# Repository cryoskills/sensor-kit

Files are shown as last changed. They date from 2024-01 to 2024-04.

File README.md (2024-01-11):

# Cryoskills 2024 - Sensor Kit
This repository contains the design notes, schematics, EDA files (KiCad), fabrication documents and firmware for the CryoSkills sensor kit.

## Folder Structure

- `design_notes/`: design notes and documentation.

- `cad/`: electronic and mechanical design files, separated into:
    - `kicad/` schematic and PCB layout files
    - `freecad/` mechanical design files

- `fabrication/`: resources required to purchase, fabricate and assemble a sensor kit (bill of materials, Gerber files, drawings, etc.).

- `firmware/`: complete and skeleton firmware for the sensor kit.

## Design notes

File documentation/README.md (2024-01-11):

See Word document for initial design notes:

    ColdEnvironmentSkillsCourse/Course content/SensorKit/SensorKit_DesignNotes.docx

Cut-down version exists in ./documentation/DesignNotes.docx

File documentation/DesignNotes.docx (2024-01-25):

# CryoSkills Sensor Kit

# System-level schematic

Solar Panel

Regulator

Battery

QWIIC (I²C) Sensors

Analogue Temp. Sensor

Micro-controller

(i.e. Feather M0 Adalogger)

SD Card

Wireless

Modem

Antenna

Weatherproof housing

Solar Regulator

Realtime clock

# Subsystems

## Power (Battery & Solar)

The power supply for the sensor kit is composed of a 12V lead-acid battery and a 12V 5W solar panel, connected to the battery through a EP Solar 5a charge controller.

Item | URL
12V 1.2Ahr lead-acid battery | https://uk.rs-online.com/web/p/lead-acid-batteries/1501558?gb=s
12V 5W solar panel | https://www.sunstore.co.uk/product/12v-5w-monocrystalline-solar-panel/
EP Solar 5a Charge Controller | https://www.sunstore.co.uk/product/ep-solar-5a-charge-controller-with-usb-output/

Table 1 - Power system components

The solar charge controller has a maximum rated battery current of 5A and maximum PV (panel) input of 30V. The mounting hole sizes are M4.5 (assumption of mm) and terminal sizes are 2.5mm² which require wire diameter of less than 1.784mm (AWG of 14 or greater). The charger user manual recommends that cables should satisfy 3.5A/mm² current density – AWG 14 can therefore accommodate 5.25A.

The battery terminals are tabs with width 4.75mm and length 6.35mm, hence a 5mm spade connector with AWG 14-16 crimp terminal is sufficient.

Finding it hard to find appropriate 4.75mm tabs in red/blue or red/black with matched 2.5mm² CSA – go with blue which has 2.5mm² max CSA.

Component | Details | Supplier | Order Code
Red 16AWG Cable | 100m | Farnell / SW | 1204343 (https://uk.farnell.com/lapp-kabel/4520041/wire-h07v-k-red-1-5mm-100m/dp/1204343)
Black 16AWG Cable | 100m | Farnell / SW | 1204340 (https://uk.farnell.com/lapp-kabel/4520011/wire-100m-1-5mm2-copper-black/dp/1204340)
Red Crimp Terminal | 4.8mm(W), 12A, 16-14AWG | Farnell / SW | 3384774 (https://uk.farnell.com/pro-power/stfdd1-187-8/female-push-on-red-12a-4-8-x-0/dp/3384774)
Blue Crimp Terminal | 4.8mm(W), 16A, 16-14AWG | Farnell / SW | 3384777 (https://uk.farnell.com/pro-power/stfdd2-187-8/female-push-on-blue-16a-4-8-x/dp/3384777)
Red Ferrule | 16 AWG 10mm | Farnell / SW | 3383565 (https://uk.farnell.com/pro-power/pet1515/german-single-ferrule-1-50mm-red/dp/3383565)
Black Ferrule | 16 AWG 10mm | Farnell / SW | 4161844 (https://uk.farnell.com/pro-power/pp01538/french-single-ferrule-1-50mm-black/dp/4161844)
Fuse Holder | 16 AWG, Red, 5x15mm Fuse, | RS Pro / SW | 849-5594 (https://uk.rs-online.com/web/p/fuse-holders/8495594)
1A Fuse | 5x15mm | - | -

Alternatively, consider using automotive blade style fuse holder & fuse – need to check options. Ideally should satisfy current rating <5A and AWG 16 gauge cable.

These place a requirement on the screw terminals used on the sensor kit PCB – they must be able to accept 1.5mm² CSA ferrules.

### Battery Capacity

The battery capacity is calculated for an on period of 2s and a sleep period of 58s, resulting in a total measurement interval of 60s. For a 24 hour period, this would yield 1440 measurements.

The average current consumed is calculated as

I=(I_(sleep) t_(sleep) +I_(peak) t_(peak) )/T_(period)

Hence for the values given in Table 2, the average current is 4.76mA at 3V3 and 6mA at 12V (solar charger). Hence the power consumed is 15.7mW (load) and 72mW (self consumption) or a total of 87.7mW. Over a period of 24hours, this requires 2.1Wh of energy. Assuming the battery is derated by 50% due to cold weather, the actual energy requirement is 4.2Wh, which at 12V equates to a battery capacity of 0.35Ah. A 12V 1.2Ah battery specified should be sufficient to run the sensor for the 24-hour period.

Component | Sleep Current (mA) @ 3V3 Vcc | Peak Current (mA) @ 3V3 Vcc | Time-enabled per cycle (s)
Adafruit Feather M0 | 2 | 20 | 2
Wireless module | 0.001 (sleep mode) | 120 | 1
I2C atmospheric sensor | 0.0000002 | 0.000714 | 1
PT1000 temp. sensor | 0.000002 | 0.210 | 1
DSB1820 temp.sensor | 0.00000075 | 1.5 | 1
I2C light sensor | 0.000005 | 0.220 | 1
Charge controller | <6 (@12V) | <6 @(12V) | Always-on
| ~8 | ~150

Table 2 - Current consumption based on subsystems

### Solar Charge Controller

Wiring of the solar charge controller is given by the (terrible user manual (https://www.sunstore.co.uk/wp-content/uploads/2017/02/LS-EU%20Manual.pdf) supplied) diagram in Figure 1.

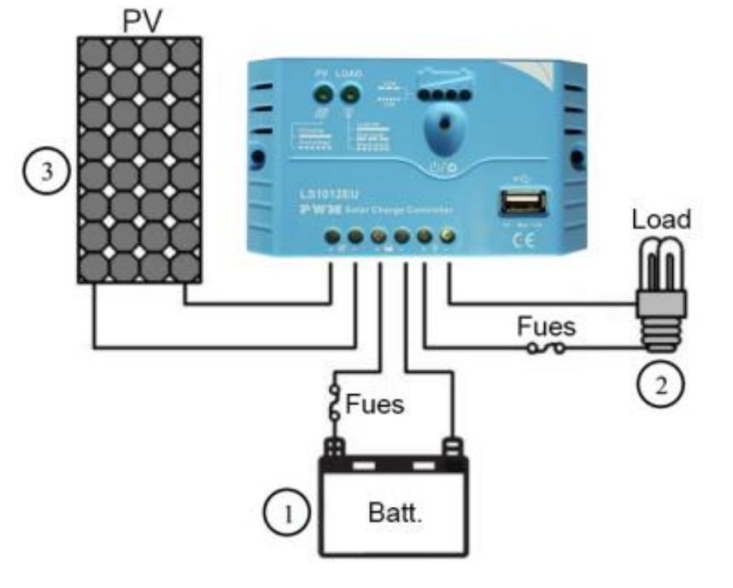
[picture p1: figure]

Figure 1 - EP Solar 5a Charge Controller wiring diagram

### INA3221 Power Meter

The Texas Instrument INA3221 (https://www.ti.com/product/INA3221) integrates a high-side ADC which can be used as a power meter. To integrate with the sensor kit, using the three available channels we can assess power from the solar panel, battery power (charge or discharge) and the power draw of the load.

Note: The rated open circuit voltage of the panel is 21.9V so this is within the maximum input voltage however it is perhaps prudent to add some voltage protection at the panel input in-case an alternative panel is used?

Appropriate current sense resistors need to be selected for each of the channels. The shunt voltage limits for the INA3221 are ±163.8mV and the maximum input voltage at any port is 26V.

We assume the peak current into the sensor kit will be on the order of 0.2A (rounded up from 0.15A peak consumption during radio transmission). With a 0.2 Ohm resistor, this equates to a shunt potential difference of 40mV (30mV) which uses approximately 10% of the full-scale voltage range.

The maximum charge current for the RS Pro lead-acid battery is listed as 0.36A, hence with the same 0.2 Ohm resistor as above, we yield a potential difference of 72 mV.

This appears to be a reasonable value to use across the application – the everythingpi.co.uk evaluation board uses 0.1 Ohm, which I assume is to accommodate for slightly higher average load currents.

A provisional wiring diagram for integrating the INA3221 power meter into the sensor kit is shown in Figure 2. This results in a total of 6x screw terminals being present on the sensor kit board, one each for the solar panel and battery and then an additional to wire the load to the solar controller. An external 6-way connector (i.e. 2x 5-way Wago?) is also necessary to provide a common ground for the panel, battery, charge controller and load.

HellermanTyton 8-way splice for 1mm² to 2.5mm² common splice (RS Stock No. 124-2530).

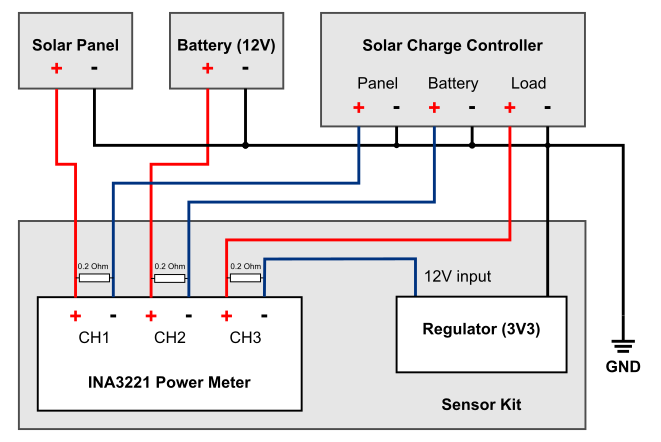
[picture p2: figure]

Figure 2 - Wiring diagram for sensor kit using INA3221 power meter with solar panel, 12V battery and solar charge controller. (Note add connector indication to diagram…)

### Linear (LDO) vs Buck Voltage Regulator

If there is a sufficient pin-for-pin replacement (3-pin 100mil, Vin-GND-Vout) for the Multicomp Pro drop-in MP-K78L03-500R3 DC/DC regulator then participants can have the choice/compare the performance of linear vs. buck boost regulated instrument using data from the INA3221. The higher efficiency DC/DC converter should draw less current from the 12V supply and hence less power.

### Mechanical Considerations (Panel)

Mounting for solar panel up to M7.5 screws through back of panel separated by 128mm height and 156mm width.

## Microcontroller and Datalogger

An Adafruit Feather M0 Adalogger has been selected as the microcontroller for the sensor kit because of the integrated MicroSD slot and compatibility with existing code. It is based on the Amtel SAMD21G18 ARM Cortex M0 processor.

Logic levels are at 3V3.

### Power Considerations

The sensor kit board has its own 3V3 regulator from the battery supply, hence the Adalogger can be powered directly from the output of the system regulator rather than its on-board 3V3 LDO (SPX3819-3.3 (https://assets.maxlinear.com/web/documents/spx3819.pdf)). This requires that the internal Adalogger 3V3 regulator is disabled by tying EN to GND and ensuring the 3V pin is connected to the output of the system regulator.

If it was desirable to use the USB to power the sensor kit (i.e. during development or testing) then a header can be fitted to connect the USB bus voltage from the Adalogger board to the sensor kit input.

Note: Either care must be taken to ensure that the battery isn’t connected at the same time as the USB power is enabled, or a physical switch is implemented on the board to ensure that this can’t take place.

For now, the second option is implemented with a slide switch to alternate between battery or USB power, using an RS Pro 734-7334 (https://uk.rs-online.com/web/p/slide-switches/7347334) SPDT On-Off-On switch.

### Pinout Table

Pin No. | Pin Name | Group | Description | Used in design
1 | NRESET | Misc | Resets on logic low (i.e. tie to GND)
2 | 3V3 | Power
3 | AREF | Analog
4 | GND | Power
5 | A0 / DAC | GPIO/Analog
6 | A1 | GPIO/Analog
7 | A2 | GPIO/Analog
8 | A3 | GPIO/Analog
9 | A4 | GPIO/Analog
10 | A5 | GPIO/Analog
11 | D24 / SCK | SPI
12 | D23 / MOSI | SPI
13 | D22 / MISO | SPI
14 | D0 / UART RX | UART
15 | D1 / UART TX | UART
16 | GND | Power
17 | D20 / SDA | I2C
18 | D21 / SCL | I2C
19 | D5 | GPIO
20 | D6 | GPIO
21 | D9 | GPIO | Also analog input A7, connected to a votage divider for the LiPo battery – avoid use.
22 | D10 | GPIO
23 | D11 | GPIO
24 | D12 | GPIO
25 | D13 | GPIO
26 | USB | Power | Output from USB 3V3 pin
27 | EN | Power | Used to disable internal 3V3 regulator.
28 | VBAT | Power

### I2C Address Table

To avoid clashes of I2C addresses, Table 3 lists the address for devices being considered or actively used in the sensor kit design.

Part No. | Description | Address | Programmable | Used in design
INA3221 (https://www.ti.com/lit/ds/symlink/ina3221.pdf?ts=1704862707360) | Power Meter | 0x40-0x43 | Yes (A0 pin) | Yes
PCF48574 (https://www.ti.com/lit/ds/symlink/pcf8574.pdf?ts=1704953203134) | 8-bit I/O expander | 0x40-0x4E | Yes (A0-2 pins) | No
BH1750 (https://thepihut.com/products/adafruit-bh1750-light-sensor-stemma-qt-qwiic) | I²C Light Sensor | 0x23 or 0x5C | Yes (ADDR pin) | ???
LTR-329 (https://thepihut.com/products/adafruit-ltr-329-light-sensor-stemma-qt-qwiic) | I²C Light Sensor | 0x29H | No | ???
BME280 (https://www.sparkfun.com/products/15440) | I2C Atmos Sensor | 0x76-0x77 | Yes (SDO pin) | ???
SparkFun Qwiic Soil (https://www.sparkfun.com/products/17731) | Soil Moiture Sensor | 0x28 | No | ???

Table 3 - I2C address table for devices used in the CryoSkills sensor kit

## Digital Temperature Sensor

The DS18B20 digital temperature sensor is available in a waterproof wired version which make it suitable for the sensor-kit application.

A datasheet describing the wired version is provided here: https://docs.rs-online.com/8ff0/A700000007238410.pdf.

It exposes a 1-wire digital interface which can be implemented with any of digital output pins of the Adafruit Feather M0 microcontroller. The DS18B20 requires three electrical connections listed in Table 4.

Wire Identifier | Description | Connected to
Red | VCC (3V3-5V) | VCC_3V3
Black | GND | GND
Yellow | Data | Adalogger D5

Table 4 - DS18B20 pinout

Note: A pull-up resistor of 4.7kOhm is required between the VCC and DATA pins.

### Mechanical Considerations

A three-way screw terminal block can be used to connect the sensor to the board, allowing easy installation through a cable gland in the sensor kit housing – no information provided on gauge of internal conductors (approximate diameter is 1mm).

The stainless-steel sensor tube is 6mm (diameter) by 35mm (length). The cable connecting the sensor to the cable is 4mm diameter.

A candidate cable gland is therefore RS Pro 822-9571 (https://uk.rs-online.com/web/p/cable-glands/8229571), rated to IP68 for cables between 3.5mm to 6mm.

Component | Details | Supplier | Order Code
DS18B20 | 3-wire digital temperature sensor | RS Components / SW | 2049893
4.7k Ohm resistor | Pull-up resistor | Farnell / SW | 2329947
3-way screw terminal
Cable gland | Suitable for 4mm diameter cable | RS Components / SW | 822-9571

## Analog Temperature Sensor (PT1000)

Cost of the RTD (resistive temperature detector) device is a main factor in the selection of the analog temperature sensor, owing to the increased cost of 3-wire and 4-wire variants.

The RS Pro 896-8399 (https://uk.rs-online.com/web/p/rtd-sensors/8968399) PT1000 RTD is a Class A two-wire RTD. A useful guide on RTD measurement circuits is provided by Texas Instruments in Application Note “A Basic Guide to RTD Measurements” (https://www.ti.com/lit/an/sbaa275a/sbaa275a.pdf).

Takeaways from the TI application note are:

- Use first-order common-mode filters at the input to ADCs to reduce common-mode noise.
- Ratiometric measurements - where the same current source is used for the RTD and the reference – remove error from current-source noise, drift and temperature effects.
- For any two-wire device, the lead resistance will affect the measurement accuracy – although at 1.5m this is likely to be minimal for a PT1000 device. It may be possible to calibrate out the effect of lead resistance.
- Keep layout in mind to ensure low-impedance current source/sink paths.

### PT1000 Characteristics

The resistance of a PT1000 sensor is given by

R_(RTD) (T)=R_0 {1+(A∙T)+(B∙T^2 )+[C∙T^3 ∙(T-100), T<01+(A∙T)+(B∙T^3 ), T>0

where the constants R_0 , A , B and C are given by

R_0 =1000 A=3.9083∙10^(-3) B=-5.775∙10^(-7) C=-4.183∙10^(-12)

Figure 3 - Nominal PT1000 resistance vs. temperature over values relevant to the CryoSkills sensor kit.

Figure 3 shows the nominal resistance for a PT1000 sensor over a temperature range of -30C to 110C which equates to a range of 882.22 to 1422.93 Ohms.

Three possible designs for the analog temperature sensing circuit are described below:

1. Turn-key solution – a Texas Instruments DAC/iDAC is used to provide a constant current source and integrated 16-bit DAC, which communicates with the Adafruit Feather M0 Adalogger over a SPI, UART or I²C interface.
2. Minimal additional peripherals – an external current source is configured to provide the reference current for the RTD but the internal ADC to the SAMD21 is used to perform the resistance calculation.
3. No additional peripherals – making use of the integrated DAC and ADC on the Atmel SAMD21 to provide a constant current source and ratiometric measurement of the RTD resistance. Requires only precision resistors to act as references.

### Turn -Key Solution

The Texas Instruments ADS1120 (https://www.ti.com/lit/ds/symlink/ads1120.pdf?ts=1704969991225) integrates a 4-channel 16-bit ADC with a maximum sampling rate of 2-kSPS with an integrated programmable gain amplifier, voltage reference and external reference input.

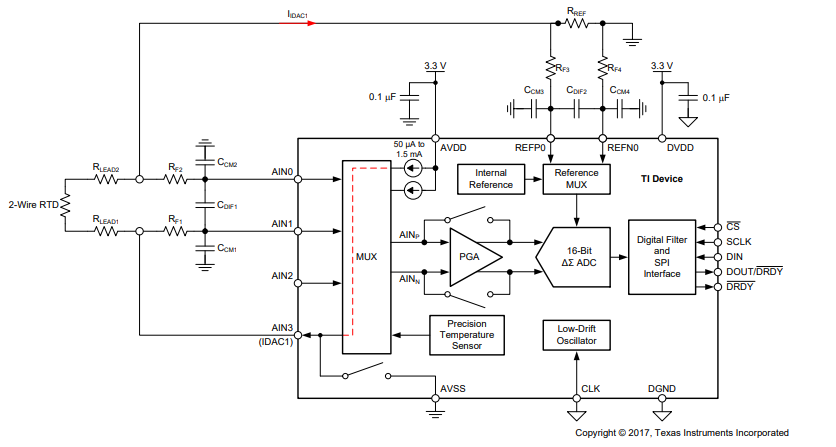
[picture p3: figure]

Figure 4 - 2-wire RTD measurement with Texas Instruments ADS1120 (Texas Instruments Incorporated © 2017)

Three interface options are available (SPI/I²C/UART) and there is a currently un-used SPI peripheral on the Adafruit Feather M0 Adalogger.

The voltage reference is limited to be within a range of 075V to AVDD (3.3V), with a nominal value of 2.5V. It is recommended to keep the excitation current below 1mA, hence for an excitation current of 500uA and a reference resistor of 1.8kOhm, the reference voltage is 0.9V which is within the valid operating range.

Note: Need to check that this value is within the compliance range for the IDAC and the input range for the PGA.

#### Common-mode and differential filters for ADC inputs

A Texas Instruments application note on design of the common-mode and differential input filters for the ADC is given in https://www.ti.com/lit/an/sbaa201a/sbaa201a.pdf?ts=1704987999288.

To choose appropriate values for the ADC input filter, a sampling rate is also required. Assuming that some averaging is completed on the microcontroller, then a sample rate of 20 SPS is sufficient for 10 noise free 16-bit samples within an operating window of 0.5s. Designing for a cutoff frequency of approximately 20 Hz therefore gives:

Differential RTD Input : f_(-3dB) =1/(2πC_(IN_DIFF) (R_(RTD) +R1+R2))

Common Mode RTD Input (high side) :f_(-3dB) =1/(2πC_(IN_CM1) (R_(RTD) +R1+R_(BIAS) ))

Common Mode RTD Input (low side) :f_(-3dB) =1/(2πC_(IN_CM2) (R2+R_(BIAS) ))

Differential bias input : f_(-3dB) =1/(2πC_(REF_DIFF) (R_(BIAS) +R3+R4))

Common Mode RTD Input (high side) :f_(-3dB) =1/(2πC_(REF_CM1) (R3+R_(BIAS) ))

Common Mode RTD Input (low side) :f_(-3dB) =1/(2πC_(REF_CM2) (R4))

To compensate the two common mode filters are each input, we require:

R2≅R1+R_(RTD) R4≅R3+R_(BIAS)

Hence, the differential input resistances become

R_(IN_DIFF) ≅2(R_(RTD) +R1) R_(IN_REF) ≅2(R_(BIAS) +R3)

Hence given that R_(BIAS) is 1.8 times the ‘mode’ (most common that might be encountered) resistance then we require that

R_(BIAS) +R3≅1.8R_(RTD) +R3≅R_(RTD) +R1 ∴R1≅0.8 R_(RTD) +R3

So that we have all the resistances defined by the ‘mode’ RTD resistance and a single variable R3 . That then leaves choosing the values of each capacitor to give the 20 Hz cutoff frequency.

R1≅0.8 R_(RTD) +R3 R2≅1.8 R_(RTD) +R3 R4≅1.8 R_(RTD) +R3 Starting with the differential cutoff frequency for the RTD input,

C_

[INCOMPLETE]

#### Component list for turn-key solution

Component | Details | Supplier | Order Code
RS PRO PT1000 RTD | 2 wire, 1.5m length | RS Components / SW | 896-8399
ADS1120 | 16-bit ADC/iDAC | Texas Instruments | ADS1120IPW (https://www.ti.com/product/ADS1120)
0603 1.8k resistor | Low temp. coefficient | Farnell / SW | 2991923 (https://uk.farnell.com/neohm-te-connectivity/8-1614881-8/res-1k8-0-1-0-063w-0603-pel-c/dp/2991923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)
[additional required for filtering]

### External Current Source Solution

Configures a LM334 as a constant current source, requiring 2x resistors for current setting and diode for temperature compensation.

Requires 1x additional precision/low temperature coefficient resistors to provide the reference voltage to implement a ratiometric temperature measurement.

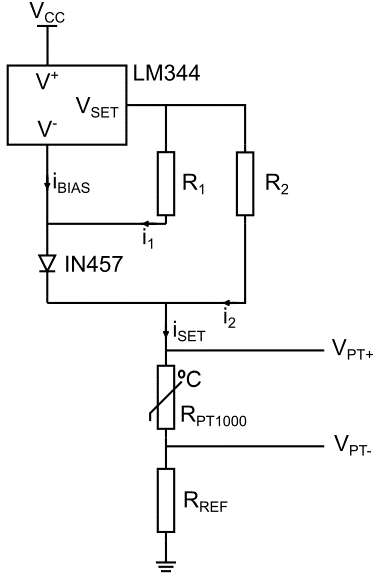
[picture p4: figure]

Table 5 - External current source PT1000 circuit

#### Calculation of R1, R2 and RREF

R1 and R2 need to be chosen to set the value of the constant current source. This material is referenced from the LM334 datasheet documentation/analog_temperature/DATASHEET_LM334.pdf – page 8. The value of RREF must then also be selected to satisfy the voltage reference requirements of the ADC.

I_(SET) =I_1 +I_2 +I_(BIAS)

I_1 =(V_(REF))/(R_1), I_2 =(V_(REF) +V_D)/(R_2)

where V_(REF) is the reference voltage of the LM334 and V_D is the diode forward voltage. No data or simulation model for the 1N457 diode forward voltage temperature coefficient is available. An alternative model 1N4149 is selected and the simulation model from Onsemi used to assess the theoretical temperature coefficient.

The materials used to derive the simulated temperature coefficient can be found in design/analog_temeprature/lm344/. The simulated temperature coefficient is 2.029 mV°C^(-1) which is smaller than the value of 2.5 mV°C^(-1) used in the LM334 datasheet example.

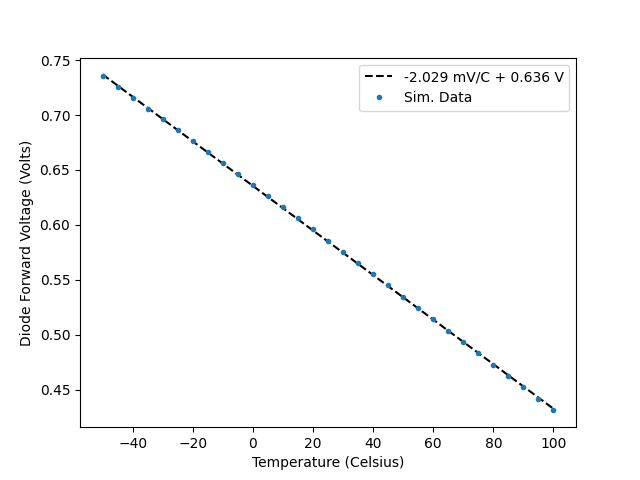
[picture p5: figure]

Table 6 – Simulated temperature coefficient for 1N4149 diode

To account for the change in the voltage reference and diode forward voltage with temperature, it is necessary to solve

(dI_(SET))/(dT)=(dI_1)/(dT)+(dI_2)/(dT) ≈(227 μV/^(∘) C)/(R_1)+(227 μV/^(∘) C-2.029mV/^(∘) C)/(R_2)=0

Therefore the ratio of R2 to R1 can be found as

(R_2)/(R_1)=(2.029 mV/^(∘) C-227 μV/^(∘) C)/(227 μV/^(∘) C)≈8.0

Continuing to follow the example laid out in the LM334 datasheet

I_(SET) =(V_R)/(R_1)+(V_R +V_D)/(R_2) I_(SET) =0.0677/(R_1)+(0.0677+0.636)/(8R_1)

I_(SET) =0.156/(R_1)

Hence to set a current of 0.5mA requires R1 is 312 Ohm and hence R2 is 2496 Ohm. Selecting E24 series values for these as 330 Ohm and 2400 Ohm, the actual current set is given as 498uA.

To set RREF with a current of 498uA, we must satisfy that the external voltage reference to the SAMD21G18 microcontroller is within the range of 1.0V to VDDANA-0.6V (1.0V to 2.7V). To exceed the minimum voltage reference by 10% (i.e. VREF of 1.1V) then RREF must be greater than 2200 Ohm. For a 1% precision 2.2k Ohm resistor, we therefore have reference voltage range of 1.08V to 1.11V which is acceptable.

Considering the resistance range of the PT1000 sensor (882 to 1422 Ohms), the output voltage range is 0.439V to 0.708V.

Increasing the reference voltage to 1.5V would allow the use of the 2x gain stage in the SAMD21 ADC which improves the dynamic range of the sensor.

An increased reference voltage of 1.5V would be achievable with a 3kOhm resistor. The total maximum voltage across the sensor chain would be approximately 2.2V.

Component | Details | Supplier | Order Code
RS PRO PT1000 RTD | 2 wire, 1.5m length | RS Components / SW | 896-8399
LM334 | Constant current source | Farnell / SW | SC18674
1N4149 | Diode | Farnell / SW | 1651147
330 Ohm | R1 | Farnell / SW | 9343032
2400 Ohm | R2 | Farnell / SW | 9342907
2200 Ohm | RREF (1) | Farnell / SW | 9342834
3000 Ohm | RREF (2) | Farnell / SW | 9342990

Table 7 - Component list for constant-current source analog temperature sensor

A candidate cable gland is therefore RS Pro 822-9571 (https://uk.rs-online.com/web/p/cable-glands/8229571), rated to IP68 for cables between 3.5mm to 6mm.

### Adalogger-only Solution

Needs 2x precision resistors (and maybe some filtering?) [to be completed].

Note: Check cable diameter of PT1000 RTD and add correct cable gland size to order

## I²C Peripheral Sensors

For each peripheral sensor type we need to consider:

- weatherproofing options and how these will affect sensor function
- calibration methods and tools required

Part No. | Description | Address | Programmable | Used in design
BH1750 (https://thepihut.com/products/adafruit-bh1750-light-sensor-stemma-qt-qwiic) | I²C Light Sensor | 0x23 or 0x5C | Yes (ADDR pin) | ???
LTR-329 (https://thepihut.com/products/adafruit-ltr-329-light-sensor-stemma-qt-qwiic) | I²C Light Sensor | 0x29H | No | ???
BME280 (https://www.sparkfun.com/products/15440) | I2C Atmos Sensor | 0x76-0x77 | Yes (SDO pin) | ???
SparkFun Qwiic Soil (https://www.sparkfun.com/products/17731) | Soil Moiture Sensor | 0x28 | No | ???

Table 8 - Summary of I2C peripheral sensors

### BH1750 – I2C Light Sensor

[section]

### LTR-329 – I2C Light Sensor

[section]

### BME280 – I2C Atmospheric Sensor

[section]

### SparkFun Qwiic Soil Moiture Sensor

[section]

## Wireless Modem

Existing libraries available for the Adafruit RFM96W LoRa module (https://uk.rs-online.com/web/p/communication-wireless-development-tools/1245502?gb=s) at 433 MHz from AirSpacey (RadioHead (https://www.airspayce.com/mikem/arduino/RadioHead/)).

If using plug & play module with 2.54mm headers, then no need for controlled impedance traces in PCB layout.

Component | Details | Supplier | Order Code
Adafruit RFM96W | LoRa 433MHz transceiver | RS Components / SW | 1245502
ANT-4WHIP3H-SMA | 433 MHz quarter-wave whip antenna | Farnell / SW | 2305892
CON-SMA-EDGE-S | SMA connector (PCB mount, 1.7mm) | Farnell / SW | 3498459
LRPS RG174 150MM | SMA bulkhead jack to SMA plug cable assembly (150mm) | Farnell / SW | 2096227

## Weatherproof Housing

[Section]

## Installation and Mounting

[Section]

# Firmware

[Section]

Sensor Kit Design Notes January 2024

CryoSkills Sensor Kit January 2024

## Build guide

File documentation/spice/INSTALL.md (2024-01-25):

# Installation instructions for ngspice
ngspice is a derivative of UC Berkeley's SPICE simulation tool.  It allows for the simulation of electronic circuits which are described by a 'netlist' file.

## Step 1 - Download ngspice
**Note:** Windows instructions only for now - but ngspice is available under different operating systems!

ngspice can be downloaded from https://ngspice.sourceforge.io/download.html.  For a Windows installation, download `ngspice-42_64.zip` and extract the folder to a relevant location on your hard drive.  For example, I've used

    C:\tools\ngspice

## Step 2 - Add to path
By following `Control Panel > Environment Variables` in the Windows system menu (or simply type 'environment variable' into the search bar), add the `bin` directory of your ngspice installation to the `PATH` variable (either User or System, depending on whether you want to install just for yourself or multiple users).

For example, with the installation directory used above, I added the following directory to my `PATH` variable:

    C:\tools\ngspice\bin

## Step 3 - Install gnuplot [optional]
gnuplot allows for quick observation of the output from ngspice simulations in the console. It can be downloaded from http://www.gnuplot.info/download.html.

I have installed version 5.4.8 (the lastest version as of writing) which comes packaged as `gp548-win64-mingw.exe`.

Run the exectuable file to install gnuplot.

Under the menu **Select Additional Tasks**, make sure that the option 'Add application to your PATH enivornment variable' is selected.

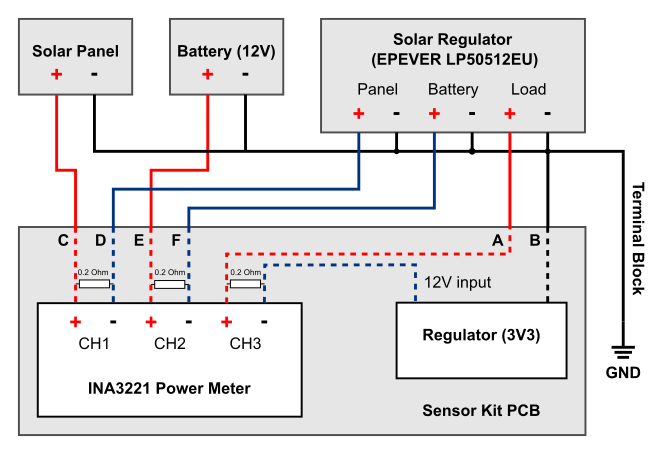
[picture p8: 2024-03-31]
documentation/power/wiring_diagram_labelled.png

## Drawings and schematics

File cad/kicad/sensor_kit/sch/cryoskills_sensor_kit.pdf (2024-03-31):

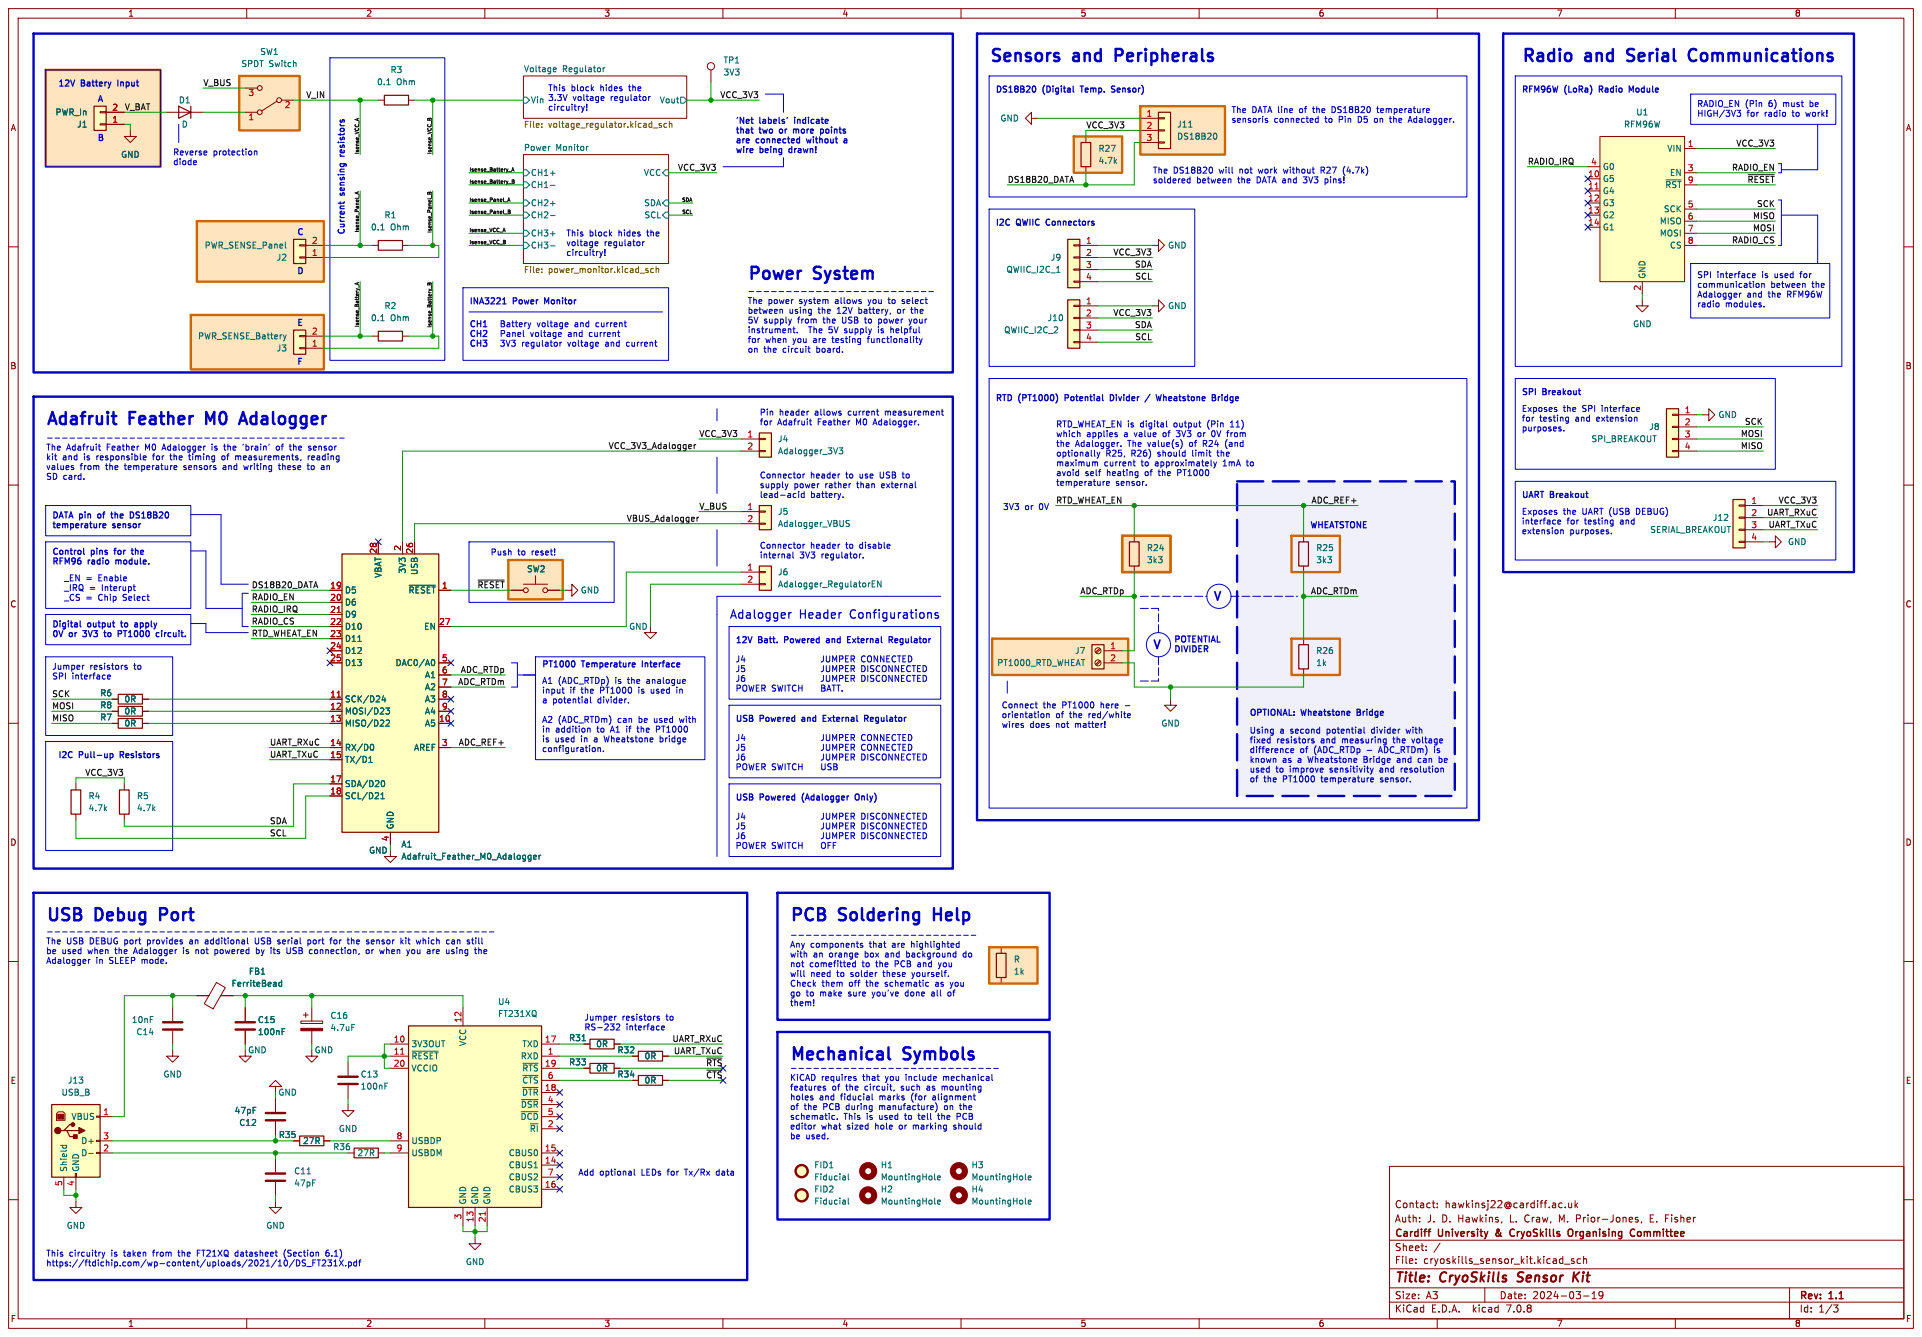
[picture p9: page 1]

RFM96W (LoRa) Radio Module Radio and Serial Communications

'Net labels' indicate
that two or more points
are connected without a wire being drawn!

SPI Breakout The DATA line of the DS18B20 temperature
J11 DS18B20 GND

radio modules. Current sensing resistors

SCL Power Monitor File: power_monitor.kicad_sch

Isense_Panel_A
for Adafruit Feather M0 Adalogger. JUMPER DISCONNECTED

D OPTIONAL: Wheatstone Bridge USB Powered and External Regulator

------------------------- The power system allows you to select between using the 12V battery, or the

5V supply from the USB to power your

F DATA pin of the DS18B20

for testing and extension

supply power rather than external

avoid self heating of the PT1000

2 D6 20 D9 21 D10 22 D11 23 D12 24 D13 25 USB 26 EN 27 VBAT 28 AREF 3 GND

Push to reset! A1 (ADC_RTDp) is the analogue

12V Batt. Powered and External Regulator J4

input if the PT1000 is used in

is used in a Wheatstone bridge

known as a Wheatstone Bridge and can be

them! PCB Soldering Help

go to make sure you've done all of

3 ~{DSR}4 ~{DCD}5 ~{CTS}6 CBUS2 7 USBDP 8 USBDM 9 U4 FT231XQ

editor what sized hole or marking should

https://ftdichip.com/wp-content/uploads/2021/10/DS_FT231X.pdf

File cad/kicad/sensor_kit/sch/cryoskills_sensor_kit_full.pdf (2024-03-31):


RFM96W (LoRa) Radio Module Radio and Serial Communications

J1 PWR_In
B Adafruit Feather M0 Adalogger
are connected without a wire being drawn! _EN = Enable

'Net labels' indicate
that two or more points

SCL Power Monitor File: power_monitor.kicad_sch

Isense_Panel_A
for Adafruit Feather M0 Adalogger. JUMPER DISCONNECTED

------------------------- The power system allows you to select between using the 12V battery, or the
radio modules. Adalogger Header Configurations
5V supply from the USB to power your

INA3221 Power Monitor DATA pin of the DS18B20

for testing and extension

supply power rather than external

avoid self heating of the PT1000

UART Breakout Exposes the UART (USB DEBUG)

2 D6 20 D9 21 D10 22 D11 23 D12 24 D13 25 USB 26 EN 27 VBAT 28 AREF 3 GND

Control pins for the RFM96 radio module.

12V Batt. Powered and External Regulator J4

configuration. PT1000 Temperature Interface
A1 (ADC_RTDp) is the analogue
input if the PT1000 is used in

is used in a Wheatstone bridge

OPTIONAL: Wheatstone Bridge
known as a Wheatstone Bridge and can be

them! PCB Soldering Help

go to make sure you've done all of

3 ~{DSR}4 ~{DCD}5 ~{CTS}6 CBUS2 7 USBDP 8 USBDM 9 U4 FT231XQ C15
GND

be used. Mechanical Symbols

editor what sized hole or marking should

https://ftdichip.com/wp-content/uploads/2021/10/DS_FT231X.pdf

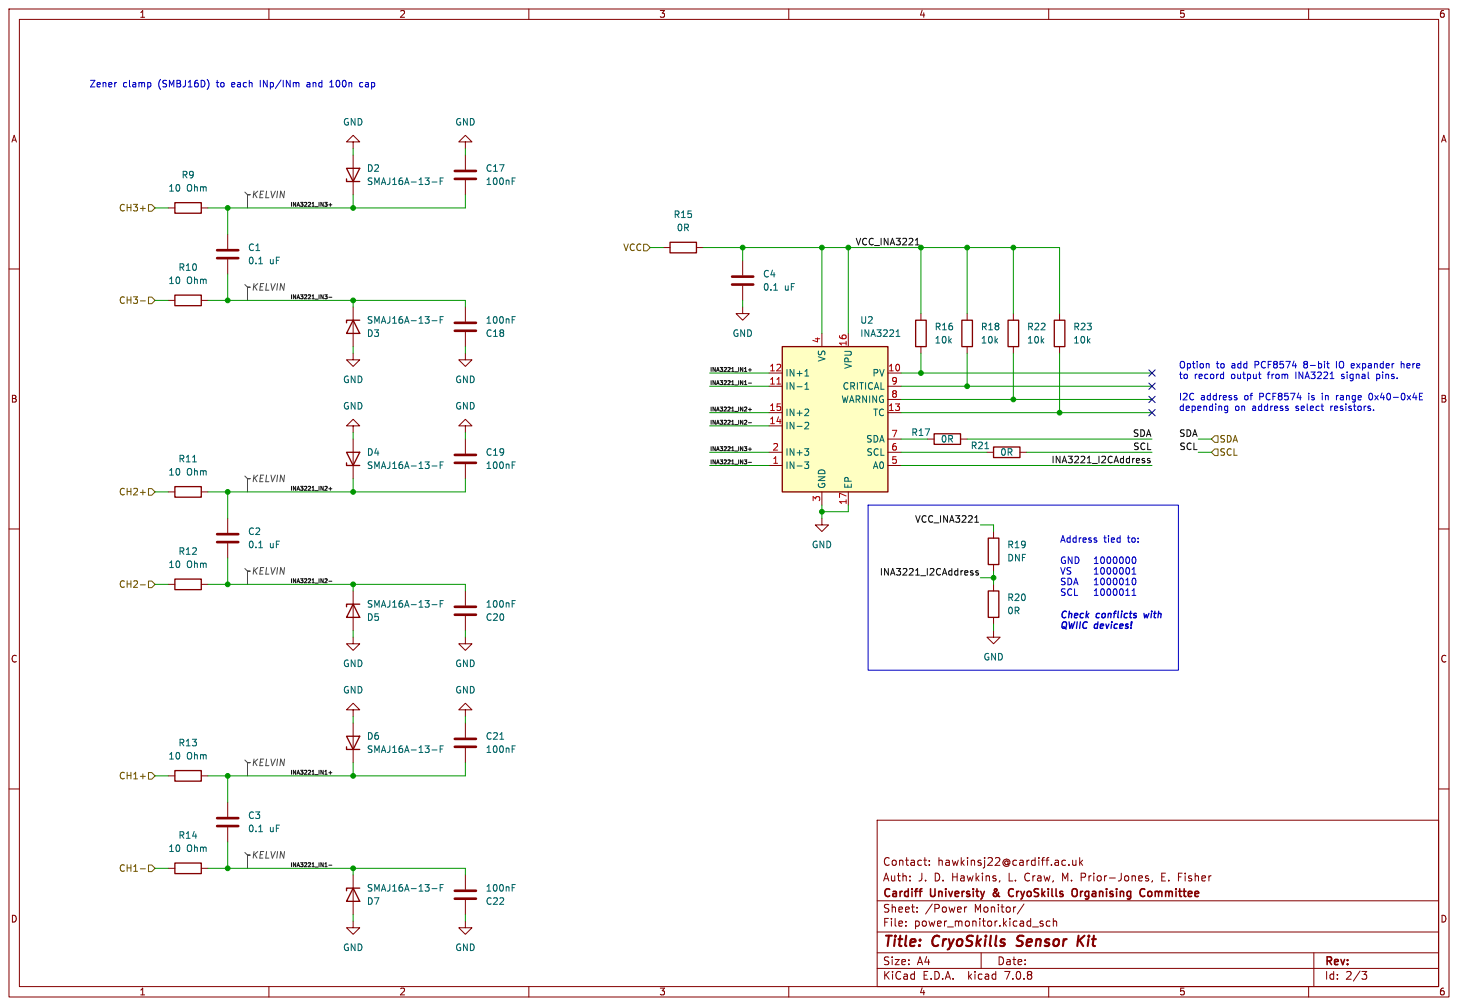
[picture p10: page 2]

4 A0 5 SCL 6 SDA 7 WARNING 8 CRITICAL 9 U2

to record output from INA3221 signal pins.

I2C address of PCF8574 is in range 0x40-0x4E

Address tied to: GND

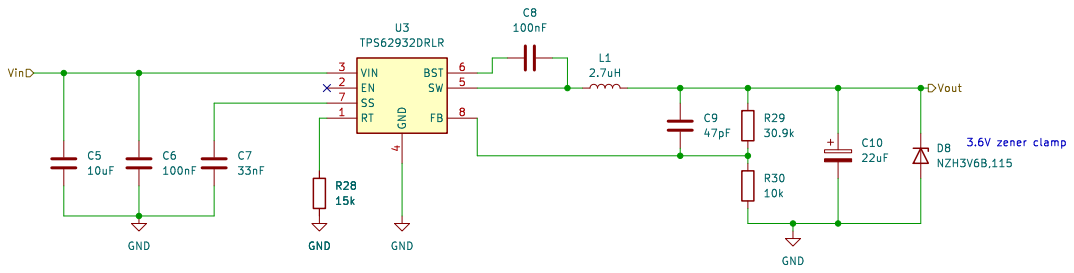
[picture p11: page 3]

4 SW 5 BST 6 SS 7 FB 8 U3 TPS62932DRLR

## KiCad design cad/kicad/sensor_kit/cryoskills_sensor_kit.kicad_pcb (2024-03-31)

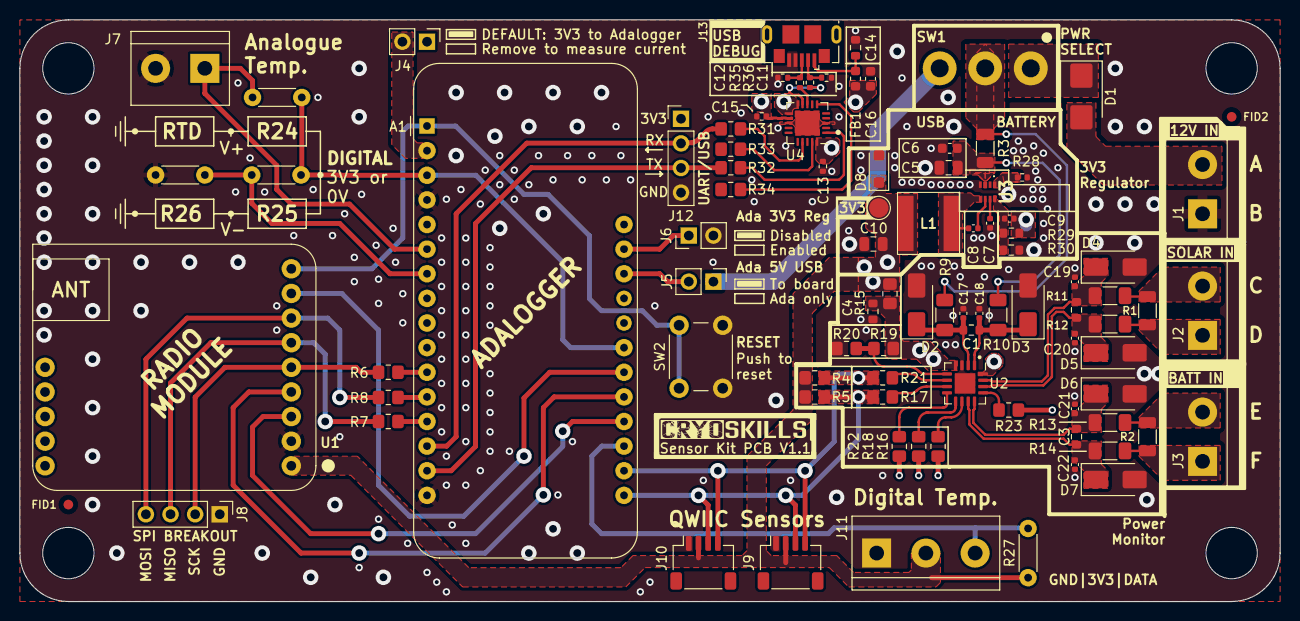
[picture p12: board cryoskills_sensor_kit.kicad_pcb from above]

Board: 2 copper layers, 130.0 x 60.0 mm, 95 parts (0 on the bottom side), 58 nets.

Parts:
A1: Adafruit_Feather_M0_Adalogger; Adafruit_Feather
C1, C2, C3, C4: 0.1 uF; R_0603_1608Metric
C5: 10uF; C_0805_2012Metric
C6: 100nF; C_0603_1608Metric
C7: 33nF; C_0402_1005Metric
C8, C17, C18, C19, C20, C21, C22: 100nF; C_0402_1005Metric
C9: 47pF; C_0402_1005Metric
C10: 22uF; C_0805_2012Metric
C11, C12: 47pF; R_0402_1005Metric
C13, C15: 100nF; R_0402_1005Metric
C14: 10nF; R_0603_1608Metric
C16: 4.7uF; C_0603_1608Metric
D1: D; D_SMB
D2, D3, D4, D5, D6, D7: SMAJ16A-13-F; D_SMA
D8: NZH3V6B,115; D_SOD-123F
FB1: FerriteBead; L_0603_1608Metric
FID1, FID2: Fiducial; Fiducial_1mm_Mask2mm
H1, H2, H3, H4: MountingHole; MountingHole_5.3mm_M5
J1: PWR_In; TerminalBlock_Multicomp_5.08_2way_MP012059
J2: PWR_SENSE_Panel; TerminalBlock_Multicomp_5.08_2way_MP012059
J3: PWR_SENSE_Battery; TerminalBlock_Multicomp_5.08_2way_MP012059
J4: Adalogger_3V3; PinHeader_1x02_P2.54mm_Vertical
J5: Adalogger_VBUS; PinHeader_1x02_P2.54mm_Vertical
J6: Adalogger_RegulatorEN; PinHeader_1x02_P2.54mm_Vertical
J7: PT1000_RTD_WHEAT; TerminalBlock_Multicomp_5.08_2way_MP012059
J8: SPI_BREAKOUT; PinHeader_1x04_P2.54mm_Vertical
J9: QWIIC_I2C_1; JST_SH_SM04B-SRSS-TB_1x04-1MP_P1.00mm_Horizontal
J10: QWIIC_I2C_2; JST_SH_SM04B-SRSS-TB_1x04-1MP_P1.00mm_Horizontal
J11: DS18B20; TerminalBlock_Multicomp_5.08_3way_MP012060
J12: SERIAL_BREAKOUT; PinHeader_1x04_P2.54mm_Vertical
J13: USB_B; USB_Micro-B_GCT_USB3076-30-A
L1: 2.7uH; 1255AY-2R7N#
R1, R2, R3: 0.1 Ohm; R_1206_3216Metric
R4, R5: 4.7k; R_0805_2012Metric_Pad1.20x1.40mm_HandSolder
R6, R7, R8, R15, R17, R20, R21, R31, R32, R33, R34: 0R; R_0805_2012Metric_Pad1.20x1.40mm_HandSolder
R9, R10, R11, R12, R13, R14: 10 Ohm; R_1206_3216Metric_Pad1.30x1.75mm_HandSolder
R16, R18, R22, R23: 10k; R_0805_2012Metric_Pad1.20x1.40mm_HandSolder
R19: DNF; R_0805_2012Metric_Pad1.20x1.40mm_HandSolder
R24, R25: 3k3; R_Axial_DIN0204_L3.6mm_D1.6mm_P5.08mm_Horizontal
R26: 1k; R_Axial_DIN0204_L3.6mm_D1.6mm_P5.08mm_Horizontal
R27: 4.7k; R_Axial_DIN0204_L3.6mm_D1.6mm_P5.08mm_Horizontal
R28: 15k; R_0402_1005Metric
R29: 30.9k; R_0603_1608Metric
R30: 10k; R_0603_1608Metric
R35, R36: 27R; R_0402_1005Metric
SW1: SPDT Switch; RSPRO_7347334_SWSlide_SPDT
SW2: SW_Push; SW_PUSH_6mm
TP1: 3V3; TestPoint_Pad_D2.0mm
U1: RFM96W
U2: INA3221; Texas_RGV_S-PVQFN-N16_EP2.1x2.1mm
U3: TPS62932DRLR
U4: FT231XQ; QFN-20-1EP_4x4mm_P0.5mm_EP2.5x2.5mm

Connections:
/ADC_REF+: A1.3 (AREF), A1.23 (D11), R24.1, R25.1
/ADC_RTDm: A1.7 (A2), R25.2, R26.1
/ADC_RTDp: A1.6 (A1), J7.1, R24.2
/DS18B20_DATA: A1.19 (D5), J11.3, R27.2
/Isense_Battery_A: J3.2, R2.2, R13.1
/Isense_Battery_B: J3.1, R2.1, R14.1
/Isense_Panel_A: J2.2, R1.2, R11.1
/Isense_Panel_B: J2.1, R1.1, R12.1
/Isense_VCC_A: R3.2, R9.1, SW1.2 (B)
/Isense_VCC_B: C5.1, C6.1, R3.1, R10.1, U3.3 (VIN)
/MISO: J8.3, R7.1, U1.6 (MISO)
/MOSI: J8.4, R8.1, U1.7 (MOSI)
/Power Monitor/INA3221_I2CAddress: R19.2, R20.1, U2.5 (A0)
/Power Monitor/INA3221_IN1+: C3.2, C21.2, D6.1 (K), R13.2, U2.12 (IN+1)
/Power Monitor/INA3221_IN1-: C3.1, C22.2, D7.1 (K), R14.2, U2.11 (IN-1)
/Power Monitor/INA3221_IN2+: C2.2, C19.2, D4.1 (K), R11.2, U2.15 (IN+2)
/Power Monitor/INA3221_IN2-: C2.1, C20.2, D5.1 (K), R12.2, U2.14 (IN-2)
/Power Monitor/INA3221_IN3+: C1.2, C17.2, D2.1 (K), R9.2, U2.2 (IN+3)
/Power Monitor/INA3221_IN3-: C1.1, C18.2, D3.1 (K), R10.2, U2.1 (IN-3)
/Power Monitor/VCC_INA3221: C4.2, R15.2, R16.1, R18.1, R19.1, R22.1, R23.1, U2.4 (VS), U2.16 (VPU)
/RADIO_CS: A1.22 (D10), U1.8 (CS)
/RADIO_EN: A1.20 (D6), U1.3 (EN)
/RADIO_IRQ: A1.21 (D9), U1.4 (G0)
/SCK: J8.2, R6.1, U1.5 (SCK)
/SCL: A1.18 (SCL/D21), J9.4, J10.4, R4.2, R21.2
/SDA: A1.17 (SDA/D20), J9.3, J10.3, R5.2, R17.2
/UART_RXuC: A1.14 (RX/D0), J12.2, R31.2
/UART_TXuC: A1.15 (TX/D1), J12.3, R32.2
/VBUS_Adalogger: A1.26 (USB), J5.2
/VCC_3V3: C9.1, C10.1, D8.1 (K), J4.1, J9.2, J10.2, J11.2, J12.1, L1.2, R4.1, R5.1, R15.1, R27.1, R29.1, TP1.1, U1.1 (VIN)
/VCC_3V3_Adalogger: A1.2 (3V3), J4.2
/V_BAT: D1.2 (A), J1.2
/V_BUS: J5.1, SW1.3 (C)
/~RESET: A1.1 (~RESET), SW2.1, U1.9 (~RST)
GND: A1.4 (GND), A1.16 (GND), C4.1, C5.2, C6.2, C7.2, C10.2, C11.1, C12.1, C13.1, C14.2, C15.1, C16.2, C17.1, C18.1, C19.1, C20.1, C21.1, C22.1, D2.2 (A), D3.2 (A), D4.2 (A), D5.2 (A), D6.2 (A), D7.2 (A), D8.2 (A), J1.1, J6.2, J7.2, J8.1, J9.1, J10.1, J11.1, J12.4, J13.4 (GND), J13.5 (Shield), R20.2, R26.2, R28.2, R30.2, SW2.2, U1.2 (GND), U2.3 (GND), U2.17 (EP), U3.4 (GND), U4.3 (GND), U4.13 (GND), U4.21 (GND)
unnamed: A1.27 (EN), J6.1
unnamed: A1.13 (MISO/D22), R7.2
unnamed: A1.12 (MOSI/D23), R8.2
unnamed: A1.11 (SCK/D24), R6.2
unnamed: D1.1 (K), SW1.1 (A)
unnamed: C12.2, J13.3 (D+), R35.1
unnamed: C11.2, J13.2 (D-), R36.1
unnamed: C14.1, FB1.1, J13.1 (VBUS)
unnamed: R21.1, U2.6 (SCL)
unnamed: R17.1, U2.7 (SDA)
unnamed: C8.1, U3.6 (BST)
unnamed: C9.2, R29.2, R30.1, U3.8 (FB)
unnamed: R28.1, U3.1 (RT)
unnamed: C7.1, U3.7 (SS)
unnamed: C8.2, L1.1, U3.5 (SW)
unnamed: C13.2, U4.10 (3V3OUT), U4.11 (~RESET), U4.20 (VCCIO)
unnamed: R32.1, U4.1 (RXD)
unnamed: R31.1, U4.17 (TXD)
unnamed: R36.2, U4.9 (USBDM)
unnamed: R35.2, U4.8 (USBDP)
unnamed: C15.2, C16.1, FB1.2, U4.12 (VCC)
unnamed: R34.1, U4.6 (~CTS)
unnamed: R33.1, U4.19 (~RTS)

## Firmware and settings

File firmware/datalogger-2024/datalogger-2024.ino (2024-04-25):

/*****************************************************************************

MIT License

Copyright (c) 2024 Cardiff University / cryoskills.com

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
*****************************************************************************/

/* ---------------- USER CONFIGURATION ---------------- */

/* Unique Sensor ID for radio packet */
#define SENSOR_ID 0xc5000000

/* Baud rate for serial communication */
#define BAUD_RATE 115200

/* Measurement interval for temperature in seconds */
#define MEASUREMENT_INTERVAL 5

/* Filename for data */
#define DATA_FILENAME "DATA.CSV"

/*
  Analogue temperature mode
  -------------------------
  Comment out the corresponding line below depending on whether you
  have the components for the Wheatstone bridge installed (R25, R26)
  or not.
*/
// Temperature mode for Wheastone bridge
// #define TEMP_MODE_WHEATSTONE
// Temperature mode for potential divider
#define TEMP_MODE_POTENTIAL

/* ---------------- PIN CONFIGURAITON ---------------- */
/* 
  DS18B20 (digital temperature sensor) Data
  -----------------------------------------
  Pin for the OneWire interface to the DS18B20 digital temperature sensor.
*/ 
#define PIN_DS18B20_DATA 5

/* 
  Wheatstone Bridge Enable
  ------------------------
  Switches the supply voltage to the potential divider/Wheatstone bridge
  circuit between 0V and 3V3.
*/  
#define PIN_WHEAT_EN 11

/* 
  Potential Divider / Wheatstone Bridge +ve Input
  -----------------------------------------------
  Analogue-to-digital converter input for the potential divider/Wheatstone 
  bridge circuit with the PT1000 resistive temperature detector.
*/
#define PIN_WHEAT_IN_POS A1

/*
  Wheatstone Bridge -ve Input
  ---------------------------
  Analogue-to-digital converter input for the fixed side of the Wheatstone
  bridge circuit.

  Only required if the full Wheatstone bridge is used.
*/
#define PIN_WHEAT_IN_NEG A2

/*
  Radio Configuration Pins
  ------------------------
  Allocates the pin for radio enable (_EN), interrupt (_IRQ) and SPI
  interface chip select (_CS).
*/
#define CRYO_PIN_RADIO_ENABLE 6
#define CRYO_RADIO_IRQ_PIN 9
#define CRYO_RADIO_CS_PIN 10

/* ---------------- INCLUDES ---------------- */
#include <Arduino.h>

#include "DS18B20.h"

#include "cryo_system.h"
#include "cryo_adc.h"
#include "cryo_radio.h"
#include "cryo_sleep.h"
#include "cryo_power.h"

/* ---------------- CONSTANT DEFINITIONS ---------------- */
/*
  Measured Resistances
  --------------------
  Store the measured resistances (to the nearest Ohm) for R24, R25, R26
*/
const uint16_t R_R24 = 3300;
const uint16_t R_R25 = 3300;
const uint16_t R_R26 = 1000;

/* Voltage Supply
   --------------
  Store the system voltge (nominally 3V3) in mV   
*/
const uint16_t V_VCC_mV = 3300;

/* ---------------- FUNCTION DELARATIONS ---------------- */

// Complete list of tasks
void datalogger_tasks();

// Temperature Functions
void do_temperature_measurements();

// PT1000 function
float get_pt1000_temperature();
  // Subroutines depending on configuration
  float get_pt1000_temperature_wheatstone();
  float get_pt1000_temperature_potential();
  // Stores the resistance to temperature conversion routine
  // in a different function
  float pt1000_resistance_to_temperature(float resistance);

// DS18B20 function
float get_ds18b20_temperature();

// SD card functions
void setup_sd_card();
void write_sd_card();

/* ---------------- PROGRAM VARIABLES ---------------- */
PseudoRTC* my_rtc;
char timestamp[CRYO_RTC_TIMESTAMP_LENGTH];

// Variables for temperature sensors
float_t temperature_ds18b20;
float_t temperature_pt1000;
int16_t adc_pt1000_raw;

// Class for DS18B20
DS18B20 my_ds18b20(PIN_DS18B20_DATA);
// store address of DS18B20 during setup call
uint64_t ds18b20_addr;

// - PT1000 analogue ADC if using Wheastone bridge
#ifdef TEMP_MODE_WHEATSTONE

ADCDifferential my_adc(
  ADCDifferential::INPUT_PIN_POS::A1_PIN,
  ADCDifferential::INPUT_PIN_NEG::A2_PIN,
  ADCDifferential::GAIN::GAIN_4X,
  ADCDifferential::AVERAGES::AVG_X256,
  ADCDifferential::RESOLUTION::RES_AVG,
  ADCDifferential::VOLTAGE_REFERENCE::INT1V_INTERNAL
);


/*
  ADC Voltage Reference
  ---------------------
  We use the default value for the ADCDifferential class of 1V0 
  however you could experiment with changing this - you will just
  need to update the value below to correspond to the valid numeric
  equivalent.

  For example:
    ADCDifferential::VOLTAGE_REFERENCE::INTVCC1_INTERNAL
    corresponds to 0.5 * VDDANA (or 3.3V in our system)
    so the correct value of ADC_VOLTAGE_REFERENCE would be
    0.5 * 3.3 * 1000 = 1650
*/
const uint16_t ADC_VOLTAGE_REFERENCE = 1000;

#endif

// Select the debug level we are using - comment out this line
// to disable debugging!
extern CRYO_DEBUG_LEVEL CRYO_DEBUG;

/* ---------------- MAIN PROGRAM ---------------- */

void setup() {

  // Define debug type
  CRYO_DEBUG = DEBUG_SERIAL_AND_SD;

  // Initialise serial communication
  Serial.begin(BAUD_RATE);
  SerialDebug.begin(BAUD_RATE);

  /* ---------------- CONFIGURE PINS ---------------- */
  // Configure analogue input if using potential divider 
  #ifdef TEMP_MODE_POTENTIAL
    pinMode(PIN_WHEAT_IN_POS, INPUT);
  #endif

  /* ---------------- INIT POWER ---------------- */
  if (!cryo_power_init()) {
    CRYO_DEBUG_MESSAGE("Failed to initialise INA3221");
    cryo_error(CRYO_ERROR_INA3221_INIT);
  }
  delay(50);

  /* ---------------- CONFIGURE RTC ---------------- */
  CRYO_DEBUG_MESSAGE("Configuring clock");
  cryo_configure_clock(__DATE__, __TIME__);

  CRYO_DEBUG_MESSAGE("Getting real-time clock");
  my_rtc = cryo_get_rtc();

  /* ---------------- INIT RADIO ---------------- */
  CRYO_DEBUG_MESSAGE("Initialising radio");
  if (!cryo_radio_init(SENSOR_ID, my_rtc)) {
    CRYO_DEBUG_MESSAGE("Failed to initialise radio");
    cryo_error(CRYO_ERROR_RADIO_INIT);
  }

  /* ---------------- SETUP SD CARD ---------------- */

  setup_sd_card();
  // TODO: Move this code into a cryo_init() function or similar
  if (CRYO_DEBUG == CRYO_DEBUG_LEVEL::DEBUG_SERIAL_AND_SD)
    cryo_add_alarm_every(CRYO_DEBUG_SD_FLUSH, _cryo_debug_sd_flush); 

  /* ---------------- SETUP PT1000 / ADC ---------------- */
  #ifdef TEMP_MODE_WHEATSTONE
    my_adc.begin();
  #endif
  pinMode(PIN_WHEAT_EN, OUTPUT);

  /* ---------------- SETUP DS18B20 ---------------- */
  if (!my_ds18b20.selectNext()) {
    CRYO_DEBUG_MESSAGE("Failed to initialise DS18B20 sensor");
    cryo_error(CRYO_ERROR_DS18B20_INIT);
  }
  // Set DS18b20 to highest resolution
  my_ds18b20.setResolution(12);

  // Reset PT1000 and DS18b20 variables
  temperature_ds18b20 = NAN;
  temperature_pt1000 = NAN;

  /* ---------------- ADD MEASUREMENT ALARM ---------------- */
  cryo_add_alarm_every(MEASUREMENT_INTERVAL, datalogger_tasks);
  
}

void loop() {
  // put your main code here, to run repeatedly:
  cryo_wakeup();
  // Serial.begin(BAUD_RATE);
  // SerialDebug.begin(BAUD_RATE);
  cryo_raise_alarms();
  cryo_sleep();
}

void datalogger_tasks() {
  // Switch on LED while doing things!
  digitalWrite(LED_BUILTIN, HIGH);

  // Store time at startup
  my_rtc->get_timestamp(timestamp);

  CRYO_DEBUG_MESSAGE("Starting temperature measurements");
  do_temperature_measurements();

  CRYO_DEBUG_MESSAGE("Writing data to SD card");
  write_sd_card();

  CRYO_DEBUG_MESSAGE("Sending data via radio");
  cryo_radio_send_packet(temperature_ds18b20, temperature_pt1000, adc_pt1000_raw);

  // switch it off when we are done
  digitalWrite(LED_BUILTIN, LOW);
}

void do_temperature_measurements() {
  CRYO_DEBUG_MESSAGE("Taking measurements");
  CRYO_DEBUG_MESSAGE("Doing digital temperature measurement");
  temperature_ds18b20 = get_ds18b20_temperature();
  CRYO_DEBUG_MESSAGE("Doing analogue temperature measurement");
  temperature_pt1000 = get_pt1000_temperature(); 
  char raw_message[32];
  sprintf(raw_message, "Digital  : %d mC", (int)(temperature_ds18b20*1000));
  CRYO_DEBUG_MESSAGE(raw_message);
  sprintf(raw_message, "Analogue : %d mC", (int)(temperature_pt1000*1000));
  CRYO_DEBUG_MESSAGE(raw_message);
  digitalWrite(LED_BUILTIN, LOW);
}

float_t get_ds18b20_temperature() {

  // Get next DS18B20 temperature sensor
  while (my_ds18b20.selectNext()) {
    // and return value when we have it
    return my_ds18b20.getTempC();
  }
  return 0;

}

float_t get_pt1000_temperature() {
  
  #ifdef TEMP_MODE_WHEATSTONE
    // Code for Wheatstone bridge
    return get_pt1000_temperature_wheatstone();
  #else
    // Code for Potential divider
    return get_pt1000_temperature_potential();
  #endif

}

float_t get_pt1000_temperature_wheatstone() {

#ifdef TEMP_MODE_WHEATSTONE
  CRYO_DEBUG_MESSAGE("Enabling voltage at potential divider");
  // Enable output to potential divider 
  digitalWrite(PIN_WHEAT_EN, HIGH);
  // Enable the ADC
  my_adc.enable();
  // Allow some settling time at the pin to compensate for any parasitic
  // capacitances
  delay(100);

  // Get result from ADC
  CRYO_DEBUG_MESSAGE("Reading ADC");
  adc_pt1000_raw = my_adc.read();
  // Get the configured gain of the ADC
  CRYO_DEBUG_MESSAGE("Writing value to string");
  char raw_message[32];
  sprintf(raw_message, "Raw ADC: %d", adc_pt1000_raw);
  CRYO_DEBUG_MESSAGE(raw_message);
  
  CRYO_DEBUG_MESSAGE("Converting gain");
  float_t gain = my_adc.get_gain_numeric();
  
  // CAREFUL - We use the constant numeric voltage reference from the definitions above
  //           change this value if you modify the ADC configuration!
  float_t voltage = ((float_t) adc_pt1000_raw) * ADC_VOLTAGE_REFERENCE / gain / 32768;
  sprintf(raw_message, "Calculate ADC voltage: %d mV", (int)voltage);
  CRYO_DEBUG_MESSAGE(raw_message);

  // Calculate RTD (+ve) voltage
  float_t voltage_pos = V_VCC_mV * R_R26 / (R_R25 + R_R26) + voltage;

  // Calculate RTD resistance
  float_t r_pt1000 = voltage_pos / (V_VCC_mV - voltage_pos) * R_R24;

  // digitalWrite(PIN_WHEAT_EN, LOW);
  my_adc.disable();
  
  // Convert to temperature
  return pt1000_resistance_to_temperature(r_pt1000);
#else
  return 0;
#endif

}

float_t get_pt1000_temperature_potential() {

#ifdef TEMP_MODE_POTENTIAL
  CRYO_DEBUG_MESSAGE("Enabling voltage at potential divider");
  // Enable output to potential divider 
  digitalWrite(PIN_WHEAT_EN, HIGH);
  // Allow some settling time at the pin to compensate for any parasitic
  // capacitances
  delay(100);

  // Get result from ADC
  CRYO_DEBUG_MESSAGE("Reading ADC");
  adc_pt1000_raw = analogRead(PIN_WHEAT_IN_POS);
  // Get the configured gain of the ADC
  CRYO_DEBUG_MESSAGE("Writing value to string");
  char raw_message[32];
  sprintf(raw_message, "Raw ADC: %d", adc_pt1000_raw);
  CRYO_DEBUG_MESSAGE(raw_message);
  
  // CAREFUL - We use the constant numeric voltage reference from the definitions above
  //           change this value if you modify the ADC configuration!
  float_t voltage = ((float_t) adc_pt1000_raw) * V_VCC_mV / 1023;
  sprintf(raw_message, "Calculated ADC voltage: %d mV", (int)voltage);
  CRYO_DEBUG_MESSAGE(raw_message);

  // Calculate RTD resistance
  float_t r_pt1000 = voltage / (V_VCC_mV - voltage) * R_R24;

  // digitalWrite(PIN_WHEAT_EN, LOW);
  
  // Convert to temperature
  return pt1000_resistance_to_temperature(r_pt1000);
#else
  return 0;
#endif

}

float_t pt1000_resistance_to_temperature(float_t resistance) {
  return (resistance - 1000) / 3.98;
}

void setup_sd_card() {

  File data_file;

  // Assign date/time callback
  SdFile::dateTimeCallback(cryo_rtc_sd_callback);

  if (!SD.exists(DATA_FILENAME)) {
    CRYO_DEBUG_MESSAGE("Data file does not exist - creating a new one!")

    data_file = SD.open(DATA_FILENAME, FILE_WRITE);
    data_file.printf("Temperature Data from CryoSkills Sensor %x\n");
    data_file.println("timestamp,temperature_ds18b20_C,temperature_pt1000_C,adc_raw_pt1000,voltage_battery_V,voltage_panel_V,voltage_load_V,current_battery_mA,current_panel_mA,current_load_mA");

    data_file.close();

  } 

}

void write_sd_card() {

  File data_file;

  CRYO_DEBUG_MESSAGE("Getting power consumption data.");
  // TODO: move this to another function
  float_t voltage_battery, voltage_panel, voltage_load;
  float_t current_battery, current_panel, current_load;

  // 
  voltage_battery = cryo_power_battery_voltage();
  voltage_panel = cryo_power_solar_panel_voltage();
  voltage_load = cryo_power_load_voltage();

  current_battery = cryo_power_battery_current() * 1000;
  current_panel = cryo_power_solar_panel_current() * 1000;
  current_load = cryo_power_load_current() * 1000;

  CRYO_DEBUG_MESSAGE("Writing temperature and power data to SD.");
  data_file = SD.open(DATA_FILENAME, FILE_WRITE);
  data_file.print(timestamp);
  data_file.print(",");
  data_file.print(temperature_ds18b20, 4);
  data_file.print(",");
  data_file.print(temperature_pt1000, 4);
  data_file.print(",");
  data_file.print(adc_pt1000_raw);
  data_file.print(",");
  data_file.print(voltage_battery, 4);
  data_file.print(",");
  data_file.print(voltage_panel, 4);
  data_file.print(",");
  data_file.print(voltage_load, 4);
  data_file.print(",");
  data_file.print(current_battery, 4);
  data_file.print(",");
  data_file.print(current_panel, 4);
  data_file.print(",");
  data_file.println(current_load, 4);
  data_file.close();

}

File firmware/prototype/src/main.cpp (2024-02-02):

#include <Arduino.h>
#include <Wire.h>
#include <OneWire.h>
#include <DS18B20.h>
#include <SparkFun_ENS160.h>
#include <SparkFunBME280.h>

/*
 Testing prototype sensor kit for Cryoskills course
 Get data from DS18B20 temperature probe and Sparkfun Environmental Combo (BME280), output to serial monitor
*/ 

// init probe objects
DS18B20 ds(5); //nb this uses the 'Arduino name' of the pin (D5)
BME280 bm; // this is connected to pins SCL and SDA

void setup() {
  Serial.begin(115200);
  Wire.begin();
  if (bm.beginI2C() == false) //Begin communication over I2C
  {
    Serial.println("Did you plug it in??");
    while(1); //Freeze
  }
}

void loop() {
  
 //get temperature value from DS probe, print to serial  
  
  while (ds.selectNext()) {
    Serial.println("Temperature probe:");
    Serial.print("Temp: ");
    Serial.println(ds.getTempC());
    Serial.println();
  }

// get environmental data from Sparkfun breakout, print to serial
  Serial.println("Environmental combo: ");
  Serial.print("Humidity: ");
  Serial.print(bm.readFloatHumidity(), 0);
  Serial.print(" Pressure: ");
  Serial.print(bm.readFloatPressure(), 0);
  Serial.print(" Alt: ");
  Serial.print(bm.readFloatAltitudeMeters(), 1);
  Serial.print(" Temp: ");
  Serial.print(bm.readTempC(), 2);
  Serial.println();
  Serial.print("\n");

// wait 1 second
  delay(1000);
}

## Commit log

2024-01-11 adds design notes for power supply and initial outline of power schematic
    [cryoskills_sensor_kit.kicad_pcb, cryoskills_sensor_kit.kicad_sch, power_monitor.kicad_sch]
2024-01-11 moves sensors to new board and adds discussion around ADS1120 based analog temp sensor to design notes.
    [cryoskills_sensor_kit.kicad_sch, power_monitor.kicad_sch, sensors.kicad_sch]
2024-01-25 adds further sensors to board layout
    [cryoskills_sensor_kit.kicad_pcb, cryoskills_sensor_kit.kicad_sch, power_monitor.kicad_sch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]
2024-01-25 adds design notes for analog temp sensor
    [adc_input_filter_calculations.xlsx, pt1000_resistance_vs_temperature_values.xlsx]
2024-01-25 adds initial schematic
2024-01-29 add skeleton code for prototype, using DS18B20 and BME280 temp sensors
2024-02-02 updates sensorkit PCB with revised pinout and wheatstone bridge circuit
    [cryoskills_sensor_kit.kicad_pcb, cryoskills_sensor_kit.kicad_sch, sensors.kicad_sch]
2024-02-16 makes small PCB modifications
    [cryoskills_sensor_kit.kicad_pcb]
2024-02-20 revises sensor board to remove current source and reduce footprint
    [cryoskills_sensor_kit.kicad_pcb, cryoskills_sensor_kit.kicad_sch, power_monitor.kicad_sch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]
2024-03-07 fixes MISO/MOSI on RFM96, swaps Dp/Dm on USB and makes pads for THT resistors bigger
    [cryoskills_sensor_kit.kicad_pcb, cryoskills_sensor_kit.kicad_sch, power_monitor.kicad_sch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]
2024-03-08 corrects MISO/MIMO silkscreen labels
    [cryoskills_sensor_kit.kicad_pcb, cryoskills_sensor_kit.kicad_sch]
2024-03-26 pushes latest version of schematic
2024-03-26 pushes correct version of schematic, not the no-power version
2024-03-31 updates production files from sensor kit materials
    [cryoskills_sensor_kit-B_Cu.gbr, cryoskills_sensor_kit-B_Fab.gbr, cryoskills_sensor_kit-B_Mask.gbr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]
2024-04-18 adds skeleton to get analogue and digital temperature with SD card debugging
2024-04-25 updates datalogger firmware (with Arduino IDE and PlatformIO files)
2024-04-25 adds MIT License to datalogger-2024.ino/main.cpp and resets sensor ID
    [datalogger-2024.ino, main.cpp]
